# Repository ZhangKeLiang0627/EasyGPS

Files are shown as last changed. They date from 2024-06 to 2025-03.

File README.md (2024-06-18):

# EASY-GPS

### 本项目基于：X-TRACK & CHAPPIE

### Author: kkl

---

视频介绍：[戳这儿:)](https://www.bilibili.com/video/BV1M44219745/)

硬件开源：[戳这里:P](https://oshwhub.com/hugego/easygps-ji-yu-esp32s3-de-gps-zhui-zong-qi)

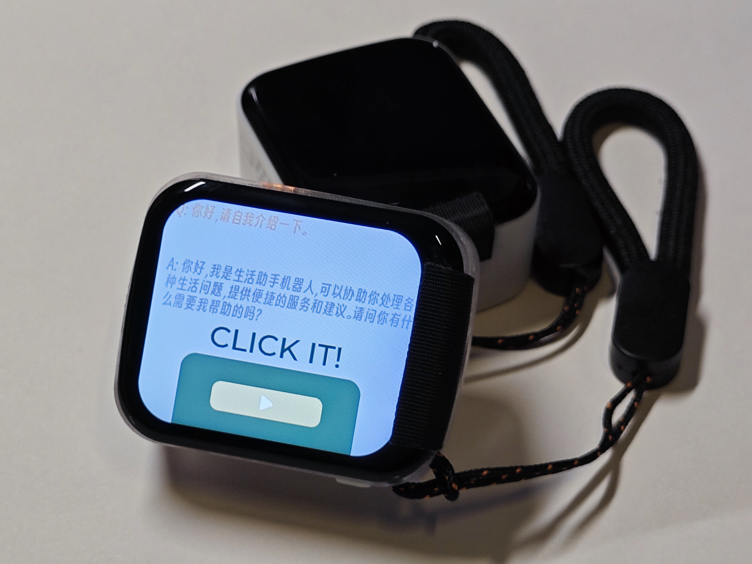
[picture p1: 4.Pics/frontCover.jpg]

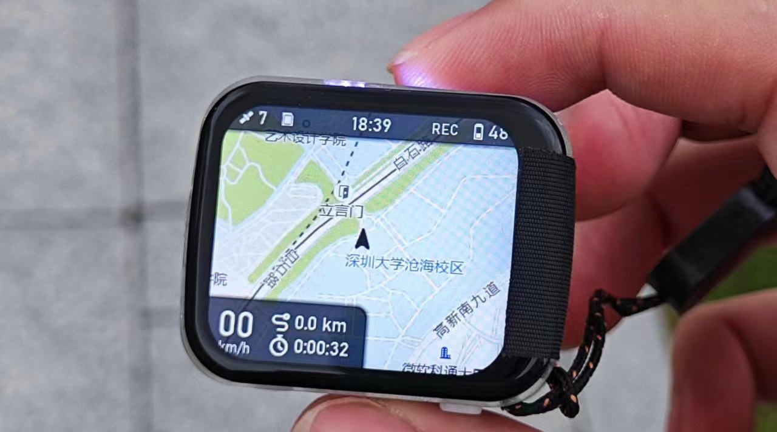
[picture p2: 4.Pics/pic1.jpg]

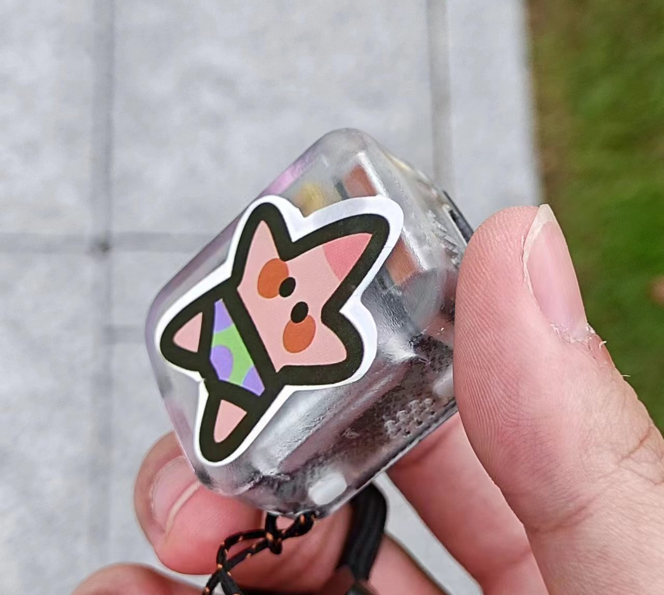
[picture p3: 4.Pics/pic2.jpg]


## 源码文件树
```bash
EasyGPS/
├─lib
│  ├─ESP32-BLE-Combo
│  ├─FastLED
│  ├─NimBLE-Arduino
│  ├─QMC5883LCompass
│  └─TinyGPSPlus
├─src
│  ├─App  
│  └─ChappieCore
├── platformio.ini
```

## TF卡文件树
```bash
MicroSDcard/
├─FONT
│  └─font_smileysd_16.bin
├─MAP
├─SystemSave.json
└─.SystemSaveBackup.json
```

## 思维导图
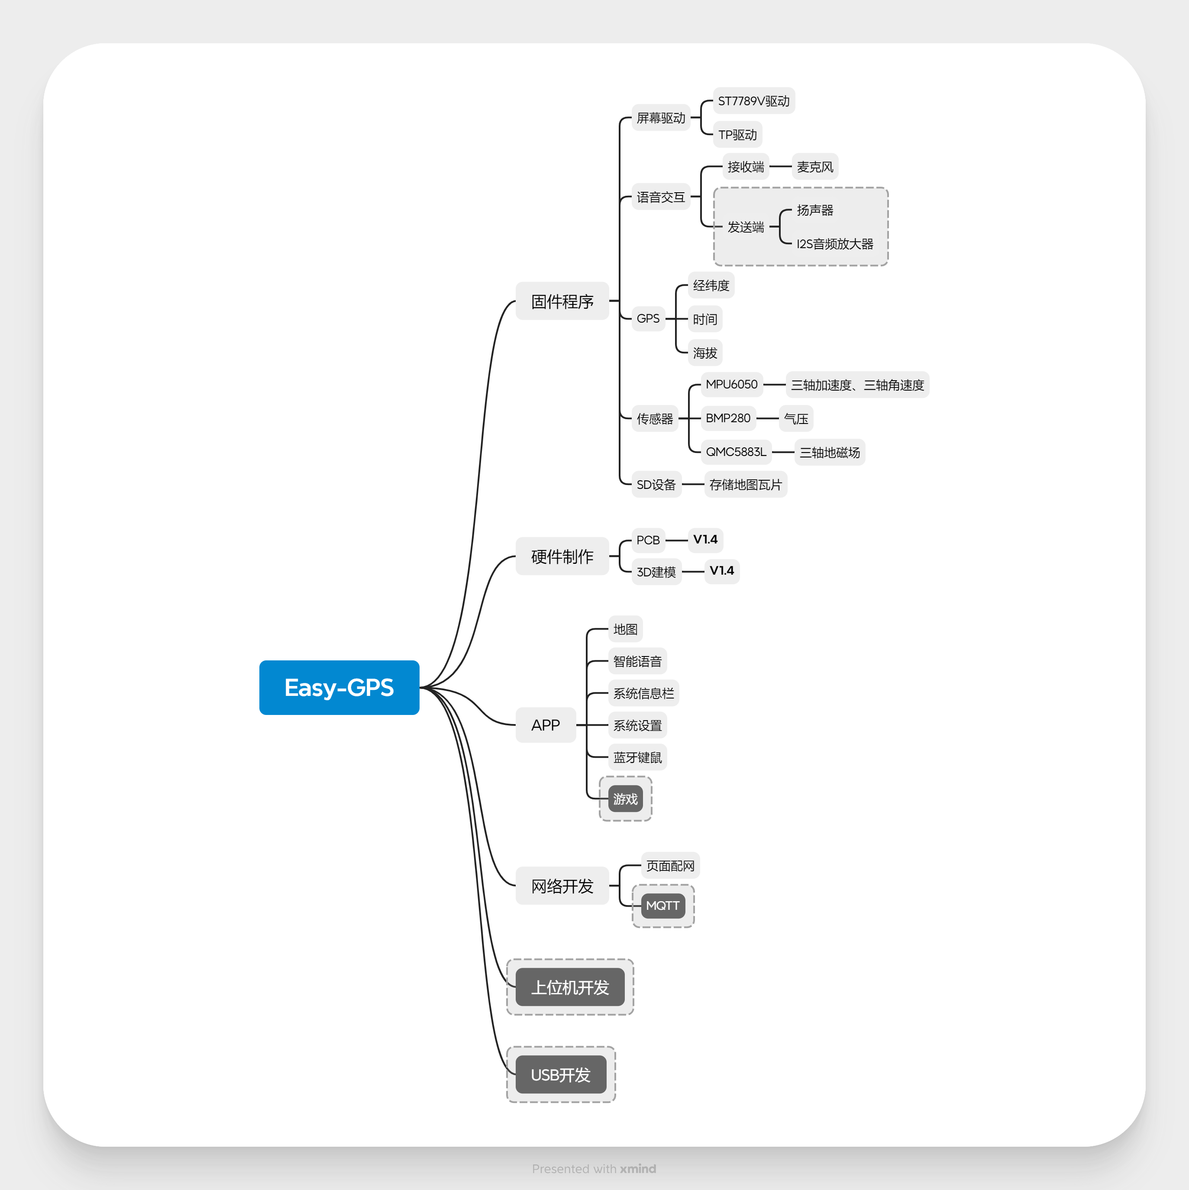
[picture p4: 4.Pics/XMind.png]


## 鸣谢
- 感谢[@FASTSHIFT](https://github.com/FASTSHIFT)的[X-TRACK](https://github.com/FASTSHIFT/X-TRACK)项目：提供了本项目的大致框架。
- 感谢[@Forairaaaaa](https://github.com/Forairaaaaa)的[Chappie-Core](https://github.com/Forairaaaaa/Chappie-Core)项目：提供了ESP32S3在Arduino开发框架的BSP，同时提供硬件的参考设计。
- 感谢[@启凡科创](https://oshwhub.com/dhx233/works)的[QF-HEYE](https://oshwhub.com/dhx233/gai-ban-re-cheng-xiang)项目：提供了部分硬件的参考设计。
- 感谢[@Yeely0162](https://github.com/Yeely0162)开源了ESP32进行WiFi连接时的Web端设计。

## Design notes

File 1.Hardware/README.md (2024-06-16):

# 【EASY-GPS】基于ESP32S3的GPS定位器 

### 本项目基于：X-TRACK & CHAPPIE

### Author: kkl

---

> 压缩包(Version: 1.4)可直接用于立创PCB下单！

视频介绍：[戳这儿:)](https://www.bilibili.com/video/BV1M44219745/)

硬件开源：[戳这里:P](https://oshwhub.com/hugego/easygps-ji-yu-esp32s3-de-gps-zhui-zong-qi)

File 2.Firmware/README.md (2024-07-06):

#### 编译该源码需要注意 lib/lv_conf.h

- 需要将 `lv_conf.h` 放在lvgl库文件夹的同一目录：  .pio/libdeps/esp32-s3-devkitc-1

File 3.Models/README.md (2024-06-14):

#### button.stl 需要修剪
- button.stl 当中有两颗按钮，我们需要将中间的连接件分离。
- 对每颗按钮的外延边进行修剪，剪成呈梯形状即可。

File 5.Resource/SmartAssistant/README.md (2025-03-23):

## 关于智能语音助手SmartAssistant的使用方法

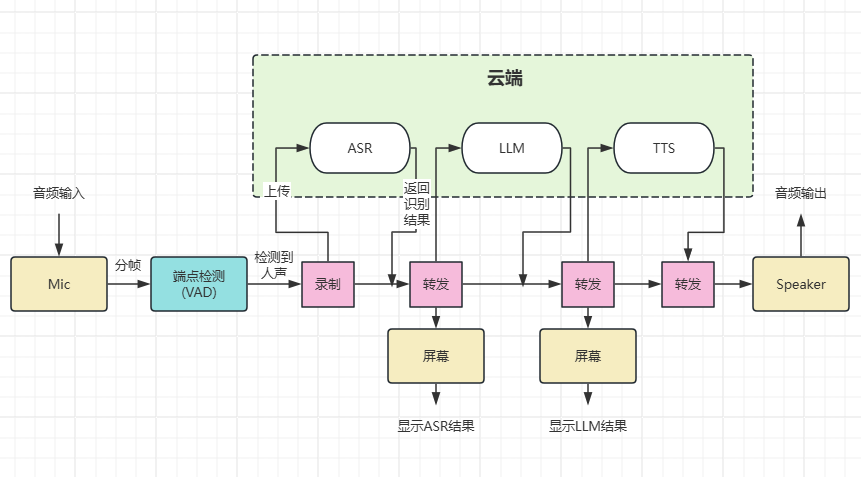
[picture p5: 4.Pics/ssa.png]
ssa流程


### 1. 获得密钥

- 百度在线语音识别 & 百度在线语音合成（共用一套密钥）

> 请您[戳这里:)](https://zhangkeliang0627.github.io/2024/03/24/ESP32S3%E6%8E%A5%E5%85%A5%E7%99%BE%E5%BA%A6%E5%9C%A8%E7%BA%BF%E8%AF%AD%E9%9F%B3%E8%AF%86%E5%88%AB/README/)了解密钥的详细获取方法！

- 文心一言API

> 请您[戳这里:)](https://zhangkeliang0627.github.io/2024/03/25/ESP32S3%E6%8E%A5%E5%85%A5%E6%96%87%E5%BF%83%E4%B8%80%E8%A8%80/README/)了解密钥的详细获取方法！

### 2. 填入密钥

请分别前往源码:
- `src/ChappieCore/SmartAssistantAPI/BaiduASR`
- `src/ChappieCore/SmartAssistantAPI/BaiduTTS`
- `src/ChappieCore/SmartAssistantAPI/BaiduErnieBot`

找到对应的`gainToken`函数，替换您自己的密钥。

### 3. 上机调试
基本上按步骤到这里就可以成功啦，如果没有成功使用智能语音助手，请考虑是否连上WiFi、密钥是否输入正确、账户是否有领取免费次数等原因。祝您复刻成功！

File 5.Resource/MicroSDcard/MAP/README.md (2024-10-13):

### 关于MAP
- 由于体积原因，请自行下载地图瓦片到此处！
- 原生项目`X-TRACK`的地图下载说明：[戳这儿!](https://github.com/FASTSHIFT/X-TRACK/tree/main/Tools)
- `Crimson/地图下载器`的下载地址：[在这儿!](https://gitee.com/CrimsonHu/java_map_download/)

### 注意事项
本项目与原生项目的地图下载大相径庭，跟着说明走就行，只有几点需要注意一下：

- 地图瓦片格式转换时注意选择`Binary RGB565`，否则在EasyGPS上显示是反色的效果。

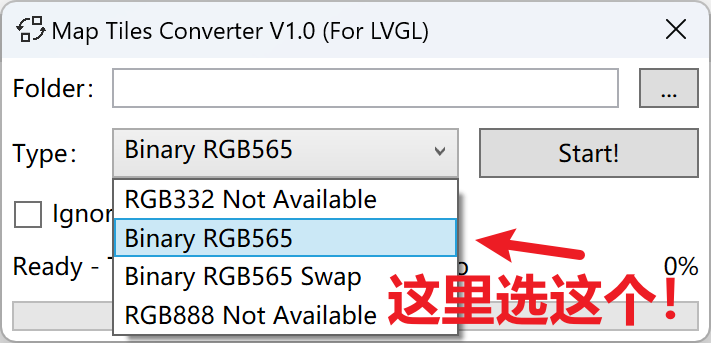
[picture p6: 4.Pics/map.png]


- SD卡的内存应当 ≤ 32GB，SD卡需要格式化为FAT32格式。

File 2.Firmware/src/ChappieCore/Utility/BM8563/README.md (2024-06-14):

Thanks to: https://github.com/tanakamasayuki/I2C_BM8563.git

# I2C BM8563 RTC Library

This is a library of BM8563, the RTC for I2C connectivity.

## Support Devices

- [M5Stack M5Stick](https://docs.m5stack.com/#/en/core/m5stickc)
- [M5Stack M5Stick Plus](https://docs.m5stack.com/#/en/core/m5stickc_plus)
- [M5Stack Core2](https://docs.m5stack.com/#/en/core/core2)
- [M5Stack Timer Camera](https://docs.m5stack.com/#/en/unit/timercam)
- [M5Stack Timer Camera X](https://docs.m5stack.com/#/en/unit/timercam_x)
- [M5Stack CoreInk](https://docs.m5stack.com/#/en/core/coreink)

## Usage
```c
#include "I2C_BM8563.h"
#include <WiFi.h>

// RTC BM8563 I2C port
// I2C pin definition for M5Stick & M5Stick Plus & M5Stack Core2 & M5Stack Core.Ink
#define BM8563_I2C_SDA 21
#define BM8563_I2C_SCL 22

// I2C pin definition for M5Stack TimerCam
// #define BM8563_I2C_SDA 12
// #define BM8563_I2C_SCL 14

I2C_BM8563 rtc(I2C_BM8563_DEFAULT_ADDRESS, Wire1);

const char* ntpServer = "time.cloudflare.com";

void setup() {
  // Init Serial
  Serial.begin(115200);
  delay(50);

  // Connect to an access point
  WiFi.begin();                 // Connect to the access point of the last connection
  //WiFi.begin("SSID", "KEY");  // Or, Connect to the specified access point

  Serial.print("Connecting to Wi-Fi ");
  while (WiFi.status() != WL_CONNECTED) {
    delay(500);
    Serial.print(".");
  }
  Serial.println(" CONNECTED");

  // Set ntp time to local
  configTime(9 * 3600, 0, ntpServer);

  // Init I2C
  Wire1.begin(BM8563_I2C_SDA, BM8563_I2C_SCL);

  // Init RTC
  rtc.begin();

  // Get local time
  struct tm timeInfo;
  if (getLocalTime(&timeInfo)) {
    // Set RTC time
    I2C_BM8563_TimeTypeDef timeStruct;
    timeStruct.hours   = timeInfo.tm_hour;
    timeStruct.minutes = timeInfo.tm_min;
    timeStruct.seconds = timeInfo.tm_sec;
    rtc.setTime(&timeStruct);

    // Set RTC Date
    I2C_BM8563_DateTypeDef dateStruct;
    dateStruct.weekDay = timeInfo.tm_wday;
    dateStruct.month   = timeInfo.tm_mon + 1;
    dateStruct.date    = timeInfo.tm_mday;
    dateStruct.year    = timeInfo.tm_year + 1900;
    rtc.setDate(&dateStruct);
  }
}

void loop() {
  I2C_BM8563_DateTypeDef dateStruct;
  I2C_BM8563_TimeTypeDef timeStruct;

  // Get RTC
  rtc.getDate(&dateStruct);
  rtc.getTime(&timeStruct);

  // Print RTC
  Serial.printf("%04d/%02d/%02d %02d:%02d:%02d\n",
                dateStruct.year,
                dateStruct.month,
                dateStruct.date,
                timeStruct.hours,
                timeStruct.minutes,
                timeStruct.seconds
               );

  // Wait
  delay(1000);
}
```

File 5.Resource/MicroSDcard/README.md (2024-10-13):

## TF卡文件树
```bash
MicroSDcard/
├─FONT
│  └─font_smileysd_16.bin
├─MAP
├─EasyGPS
├─SystemSave.json
└─.SystemSaveBackup.json
```

## 提醒
- 请按照上述文件夹格式制作您的TF卡内容。
- 地图功能和智能语音助手需要使用TF卡资源，请插卡后使用。
- 请在制作TF卡内容时手动创建`EasyGPS`文件夹，创建完成后用于保存路径轨迹`gpx`格式文件，**请手动创建，否则无法正常保存轨迹文件。**

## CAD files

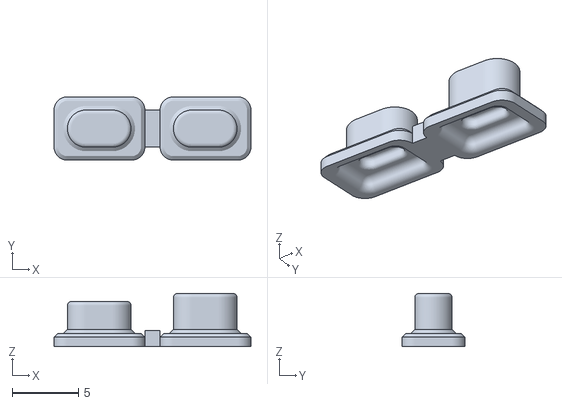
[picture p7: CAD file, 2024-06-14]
3.Models/button.stl
14.9 x 4.77 x 4.00

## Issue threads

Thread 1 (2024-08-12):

question

skipguy, 2024-08-12:
请问我把硬件组装好，然后把TF卡里的文件放好，EasyGPS就可以用了吗，非科班，不太懂代码，但是想尝试复现一下哈
还有一个问题，就是如果没有裝气压和地磁场的模块，那么其他功能还可以正常运行吗，感觉导航这两者用处不大

ZhangKeLiang0627, 2024-08-12:
> 请问我把硬件组装好，然后把TF卡里的文件放好，EasyGPS就可以用了吗，非科班，不太懂代码，但是想尝试复现一下哈 还有一个问题，就是如果没有裝气压和地磁场的模块，那么其他功能还可以正常运行吗，感觉导航这两者用处不大

A：1. 组装好硬件，安装好TF卡后，还需要对芯片进行烧录，您需要将仓库当中的firmware进行编译，编译平台是PlatformIO+Arduino；2. 没有安装上述模块，其他功能也可以正常运行的。

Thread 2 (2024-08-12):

another

skipguy, 2024-08-12:

skipguy, 2024-08-12:
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
大佬，请问BOM里第10个元件《Short_0.6》具体是什么呀，我在淘宝和立创商城是都没有找到，能否指条明路，谢谢！

skipguy, 2024-08-13:
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
佬，q请问这里的tp驱动具体是指什么呀，没能在bom中找到

ZhangKeLiang0627, 2024-08-13:
@skipguy A: 1. Short_0.6是短接焊盘，是当你焊接完成后，上电测试确保VBUS无短路，同时电源管理芯片正常工作时，用焊锡将这个焊盘进行短接即可，作用是防止短路发生时连带烧坏主控等一众芯片；2. TP驱动是指TouchPad，触摸驱动，这个模块已经集成在屏幕当中，不需要理会。

skipguy, 2024-08-18:
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
大佬可以分享下这个文件吗，我元件都买来了，但是不知道哪个焊哪里，请问有没有电子元件对应位置的图？

skipguy, 2024-08-18:
哦，大佬。我已经找到了，谢谢你

ZhangKeLiang0627, 2024-08-19:
> 哦，大佬，我已经找到了，谢谢你的开源！！！给我这个暑假提供了最大的乐趣！

谢谢你的喜欢！

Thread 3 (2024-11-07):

lv_config.h文件夹放置路径导致的编译错误问题

jhnmyr233, 2024-11-07:
当其位于：2.Firmware\lib\lv_conf.h，编译导致出错，如图。
将其位置更改为：2.Firmware\.pio\libdeps\esp32-s3-devkitc-1\lvgl\src\lv_conf.h ，方可成功编译。
我在其他的使用platformio管理的项目中也遇到过类似的问题，比较玄学，希望您可以在您的环境下测试一下，看看是什么结果。
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

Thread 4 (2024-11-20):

LCD与TFcard硬件引脚功能未注明

jhnmyr233, 2024-11-20:
引脚如下:

- LCD_CS
- LCD_BL
- LCD-DC
- LCD-SCL
- LCD-SDA
- LCD-RST
- TP-SCL
- TP-SDA
- TP-RST
- TP-INT
- LCD-EN

部分引脚命名与ST7789V数据手册内的引脚注名不相符，我到现在没理清头绪 :(
出于代码改动的需求，希望作者能够对每个引脚做一下功能标注。
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

ZhangKeLiang0627, 2024-11-21:
朋友你好:)，关于你的提问，我也一时无法详细地参照ST7789V芯片手册给到你回答。但是引脚的命名我是参照屏幕厂家给出的引脚定义的，希望能给到你一些参考，如图：
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

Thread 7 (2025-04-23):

WiFi、AP & BLE 功能打开后导致 ESP32 重启

yuangezhizao, 2025-04-23:
环境：正面元件全部焊接，背面没有焊接，因此源码中注释了`// Gps.init();`和`// Sd.init();`
烧录后发现`WiFi`相关报错，`RT`，于是又注释了`Wf.Init();`，其他源码没有任何修改
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

复现：测试各个传感器发现，在屏幕上进入语音助手会导致重启，报错堆栈如下
``` bash
Guru Meditation Error: Core  1 panic'ed (LoadProhibited). Exception was unhandled.

Core  1 register dump:
PC      : 0x42012bd6  PS      : 0x00060e30  A0      : 0x82032902  A1      : 0x3fcc2780
A2      : 0x00000000  A3      : 0x3fcc27d0  A4      : 0xa4e8aa18  A5      : 0x0000003a
A6      : 0xffff3fff  A7      : 0x00000001  A8      : 0xe27256ac  A9      : 0x0000ffdc
A10     : 0xfffffff0  A11     : 0x3fcc29d4  A12     : 0x00000000  A13     : 0x00080000
A14     : 0x00000018  A15     : 0x3fca6648  SAR     : 0x00000020  EXCCAUSE: 0x0000001c
EXCVADDR: 0xe27256ac  LBEG    : 0x4203466c  LEND    : 0x42034679  LCOUNT  : 0x00000003

Backtrace: 0x42012bd3:0x3fcc2780 0x420328ff:0x3fcc27a0 0x420329be:0x3fcc27d0 0x4203508a:0x3fcc2800 0x42035476:0x3fcc2840 0x42036ea8:0x3fcc2880 0x420377c1:0x3fcc2920 0x4211f43e:0x3fcc2990 0x42025e71:0x3fcc29b0 0x42025fdb:0x3fcc29d0 0x4202d92e:0x3fcc2a10 0x4202dfb7:0x3fcc2a40 0x4202e7ba:0x3fcc2a60 0x42010481:0x3fcc2a80 0x420106f3:0x3fcc2aa0 0x4200ff8e:0x3fcc2f00 0x420156de:0x3fcc2f20 0x420157ee:0x3fcc2f70 0x420152a5:0x3fcc2f90 0x42015639:0x3fcc2fb0 0x4201210b:0x3fcc2fe0 0x42025f45:0x3fcc3000 0x42025fdb:0x3fcc3020 0x420267c3:0x3fcc3060 0x42027110:0x3fcc30a0 0x40377453:0x3fcc30f0 0x4201aaae:0x3fcc3120

ELF file SHA256: 374021e525d0ba0e

Rebooting...
ESP-ROM:esp32s3-20210327
Build:Mar 27 2021
rst:0xc (RTC_SW_CPU_RST),boot:0xb (SPI_FAST_FLASH_BOOT)
Saved PC:0x42123b36
SPIWP:0xee
mode:DIO, clock div:1
load:0x3fce3808,len:0x44c
load:0x403c9700,len:0xbe4
load:0x403cc700,len:0x2a68
entry 0x403c98d4
[Power] Voltage:4.30 V
```

排查：翻立创帖子以为是需要先配网才能用语音助手，于是尝试在屏幕上开启`AP`发现又重启了，后发现开启 WiFi、AP 和 BLE 的开关后都会导致重启（代码中调用`Wf.Init();`,`Wf.APMode();`之类的就会），但是看不到具体报错堆栈……

不太会用`ESP32`的`debug`，打了断点却停在了奇怪的位置，`USB`串口还无了，重新使用`TTL`烧录固件后才能用`USB`串口，请问应该如何排查？

yuangezhizao, 2025-04-23:
再确认下`π`网络的取值，最开始我给`R25`和`R26`焊接了`0Ω`电阻，后来发现应该是空着不焊接吧
立创的帖子`0Ω`电阻指的是`R23`吧，最开始是理解错了

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

ZhangKeLiang0627, 2025-04-23:
您好，感谢提出问题。

设备倘若要使用WiFi、GPS、BLE是需要接入电池（默认3.7V的锂电池600mAh，刚好塞满外壳内部空间）的，否则会因为供电不足而导致ESP32重启。

仓库当中有提到，如果您要使用地图和智能语音对话助手功能，是需要使用到SD卡内的资源的，这要求您将仓库内与SD卡相关的内容拷贝到您的SD卡当中并插入设备后再启动，使之能够读取加载SD卡中的资源（主要是中文字库）。没有加载字库无法打开语音对话助手应用，会报错而重启。

智能语音助手功能需要您去配置对应百度智能云的ASR+TTS、LLM的Key，并按照仓库当中的说明指引填到源代码的对应位置去才可启用智能语音助手。

ZhangKeLiang0627, 2025-04-23:
> 再确认下`π`网络的取值，最开始我给`R25`和`R26`焊接了`0Ω`电阻，后来发现应该是空着不焊接吧 立创的帖子`0Ω`电阻指的是`R23`吧，最开始是理解错了
>
> 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

对的，0Ω电阻指的是R23

yuangezhizao, 2025-04-26:
前几天把背面元件全部焊接完成并插入电池后，`WiFi`、`AP`&`BLE`功能就可以正常使用了，看来确实是供电不足 :(
P.S. 这个`CA-C03`贴片天线信号看起来应该是正常的吧，和`AP`是在同一间屋子里，信号强度`-33dbm`

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

<hr>

最后，想再问下是一定需要接入电池还是如果`USB`供电足够就可以支撑？
看原理图上`USB`的`VBUS`输入经过`SGM4056`给到`BAT`，然后给`ESP32`供电的`VDD3V3`是电池输入经过`SGM6036`后得到的吧
所以，是没接入电池时`SGM4056`的输出不够？不知道我理解的对不对

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

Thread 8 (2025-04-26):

使用 SmartAssistant 中 ASR 报错后，疑似内存不足导致 ESP32 重启

yuangezhizao, 2025-04-26:
环境：`BaiduASR.cpp`中配置好了`client_id`和`client_secret`后烧录程序，账户中有「短语音识别极速版」的免费额度，但是目前只配置了`ASR`

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

<hr>

复现：开机后首先连接`WiFi`，然后进入`SmartAssistant`功能

- 第一次，报错`token`失效，奇怪`token`应该是存在`Preferences`中的，而不用每次重启时都要重新获取吧

<details>

``` bash
LocalIP:192.168.2.242
[DP] WiFiPULL
[Model] GetWiFiInfo
[DP] BLE PULL
[Model] GetBLEInfo
[DP] BacklightPULL
[Model] GetDisplayBrightness
[Power] Voltage: 3.64 V
[Power] Voltage: 3.63 V
[DP] SmartAssistantPULL
[Model] GetSmartAssistantInfo
[DP] SmartAssistantPULL
[Model] GetSmartAssistantInfo
[DP] SmartAssistantNOTOFIY
Helloworld and none!
[Talk] Talk Start!
[Mic] Record begin!
[Model] SetSmartAssistantBegin
[Mic] record: true count: 0
[Mic] rms:16704.99
[Mic] record: true count: 1
[Mic] rms:1196.53
[Mic] record: true count: 2
[Mic] rms:1206.58
[Mic] record: true count: 3
[Mic] rms:1208.49
[Mic] record: true count: 4
[Mic] rms:1205.96
[Mic] record: true count: 5
[Power] Voltage: 3.63 V
[Mic] rms:1205.36
[Mic] record: true count: 6
[Mic] rms:1207.05
[Mic] record: true count: 7
[DP] SmartAssistantPULL
[Model] GetSmartAssistantInfo
[Mic] rms:1205.74
[Mic] record: true count: 8
[Mic] rms:1208.12
[Mic] record: true count: 9
[Mic] rms:1205.86
[Mic] record: true count: 10
[Mic] rms:1206.78
[Mic] record: true count: 11
[Mic] rms:1204.41
[Mic] record: true count: 12
[Mic] rms:1205.42
[Mic] record: true count: 13
[Mic] rms:1206.40
[Mic] record: true count: 14
[Mic] rms:1207.74
[Mic] record: true count: 15
[Mic] rms:1206.70
[Mic] record: true count: 16
[Mic] rms:1205.19
[Mic] record: true count: 17
[Mic] rms:1204.32
[Mic] record: true count: 18
[Mic] rms:1204.38
[Mic] record: true count: 19
[Mic] rms:1204.86
[Mic] record: true count: 20
[Mic] rms:1203.60
[Mic] record: true count: 21
[Mic] rms:1204.81
[Mic] record: true count: 22
[DP] SmartAssistantPULL
[Model] GetSmartAssistantInfo
[Mic] rms:1206.05
[Mic] record: true count: 23
[Mic] rms:1206.40
[Mic] record: true count: 24
[Mic] rms:1206.58
[Mic] record: true count: 25
[Mic] rms:1205.45
[Mic] record: true count: 26
[Mic] rms:1203.86
[Mic] record: true count: 27
[Mic] rms:1205.02
[Mic] record: true count: 28
[Mic] rms:1205.83
[Mic] record: true count: 29
[Mic] rms:1205.05
[Mic] record: true count: 30
[Mic] rms:1204.22
[Mic] record: true count: 31
[Mic] rms:1205.85
[Mic] record: true count: 32
[Mic] rms:1203.97
[Mic] record: true count: 33
[Mic] rms:1207.03
[Mic] record: true count: 34
[Mic] rms:1207.41
[Mic] record: true count: 35
[Mic] rms:1205.19
[Mic] record: true count: 36
[Mic] rms:1204.88
[Mic] record: true count: 37
[Power] Voltage: 3.63 V
[Mic] rms:1204.25
[Mic] record: true count: 38
[DP] SmartAssistantPULL
[Model] GetSmartAssistantInfo
[Mic] rms:1206.36
[Mic] record: true count: 39
[Mic] rms:1205.87
[Mic] record: true count: 40
[Mic] rms:1203.81
[Mic] record: true count: 41
[Mic] rms:1205.49
[Mic] record: true count: 42
[Mic] rms:1203.24
[Mic] record: true count: 43
[Mic] rms:1206.33
[Mic] record: true count: 44
[Mic] rms:1205.16
[Mic] record: true count: 45
[Mic] rms:1203.91
[Mic] record: true count: 46
[Mic] rms:1201.70
[Mic] record: true count: 47
[Mic] rms:1207.98
[Mic] record: true count: 48
[Mic] rms:1204.68
[Mic] record: true count: 49
[Mic] rms:1204.61
[Mic] record: true count: 50
[Mic] rms:1206.35
[Mic] record: true count: 51
[Mic] rms:1207.26
[Mic] record: true count: 52
[Mic] rms:1205.44
[Mic] record: true count: 53
[Mic] rms:1205.68
[Mic] record: true count: 54
[DP] SmartAssistantPULL
[Model] GetSmartAssistantInfo
[Mic] rms:1205.31
[Mic] record: true count: 55
[Mic] rms:1205.20
[Mic] record: true count: 56
[Mic] rms:1203.95
[Mic] record: true count: 57
[Mic] rms:1205.91
[Mic] record: true count: 58
[Mic] rms:1205.05
[Mic] record: true count: 59
[Mic] rms:1206.48
[Mic] record: true count: 60
[Mic] rms:1204.74
[Mic] record: true count: 61
[Mic] rms:1205.49
[Mic] record: true count: 62
[Mic] rms:1205.11
[Mic] record: true count: 63
[Mic] rms:1207.64
[Mic] record: true count: 64
[Mic] rms:1204.83
[Mic] record: true count: 65
[Mic] rms:1204.68
[Mic] record: true count: 66
[Mic] rms:1206.24
[Mic] record: true count: 67
[Mic] rms:1205.31
[Mic] record: true count: 68
[Power] Voltage: 3.65 V
[Mic] rms:1205.31
[Mic] record: true count: 69
[DP] SmartAssistantPULL
[Model] GetSmartAssistantInfo
[Mic] rms:1204.30
[Mic] record: true count: 70
[Mic] rms:1205.34
[Mic] record: true count: 71
[Mic] rms:1202.89
[Mic] record: true count: 72
[Mic] rms:1202.31
[Mic] record: true count: 73
[Mic] rms:1206.99
[Mic] record: true count: 74
[Mic] rms:1205.25
[Mic] record: true count: 75
[Mic] rms:1204.32
[Mic] record: true count: 76
[Mic] rms:1205.30
[Mic] record: true count: 77
[Mic] rms:1206.55
[Mic] record: true count: 78
[Mic] rms:1203.85
[Mic] record: true count: 79
[Mic] rms:1202.96
[Mic] record: true count: 80
[Mic] rms:1205.43
[Mic] record: true count: 81
[Mic] rms:1205.37
[Mic] record: true count: 82
[Mic] rms:1203.25
[Mic] record: true count: 83
[Mic] rms:1205.04
[Mic] record: true count: 84
[Mic] rms:1204.04
[Mic] record: true count: 85
[DP] SmartAssistantPULL
[Model] GetSmartAssistantInfo
[Mic] rms:1205.22
[Mic] record: true count: 86
[Mic] rms:1205.75
[Mic] record: true count: 87
[Mic] rms:1204.86
[Mic] record: true count: 88
[Mic] rms:1203.87
[Mic] record: true count: 89
[Mic] rms:1203.06
[Mic] record: true count: 90
[Mic] rms:1206.96
[Mic] record: true count: 91
[Mic] rms:1205.90
[Mic] record: true count: 92
[Mic] rms:1205.69
[Mic] record: true count: 93
[Mic] rms:1202.16
[Mic] record: true count: 94
[Mic] rms:1204.39
[Mic] record: true count: 95
[Mic] rms:1203.93
[Mic] record: true count: 96
[Mic] rms:1206.57
[Mic] record: true count: 97
[Mic] rms:1206.19
[Mic] record: true count: 98
[Mic] rms:1206.50
[Mic] record: true count: 99
[Mic] rms:1205.87
[Mic] record: true count: 100
[Power] Voltage: 3.63 V
[Mic] rms:1205.69
[Mic] record: true count: 101
[DP] SmartAssistantPULL
[Model] GetSmartAssistantInfo
[Mic] rms:1205.98
[Mic] record: true count: 102
[Mic] rms:1203.46
[Mic] record: true count: 103
[Mic] rms:1204.44
[Mic] record: true count: 104
[Mic] rms:1205.41
[Mic] record: true count: 105
[Mic] rms:1205.57
[Mic] record: true count: 106
[Mic] rms:1205.46
[Mic] record: true count: 107
[Mic] rms:1206.29
[Mic] record: true count: 108
[Mic] rms:1206.34
[Mic] record: true count: 109
[Mic] rms:1205.13
[Mic] record: true count: 110
[Mic] rms:1205.78
[Mic] record: true count: 111
[Mic] rms:1203.58
[Mic] record: true count: 112
[Mic] rms:1205.79
[Mic] record: true count: 113
[Mic] rms:1205.48
[Mic] record: true count: 114
[Mic] rms:1206.71
[Mic] record: true count: 115
[Mic] rms:1204.60
[Mic] record: true count: 116
[DP] SmartAssistantPULL
[Model] GetSmartAssistantInfo
[Mic] rms:1204.43
[Mic] record: true count: 117
[Mic] rms:1206.43
[Mic] record: true count: 118
[Mic] rms:1205.12
[Mic] record: true count: 119
[Mic] rms:1207.12
[Mic] record: true count: 120
[Mic] rms:1203.98
[Mic] record: true count: 121
[Mic] rms:1207.49
[Mic] record: true count: 122
[Mic] rms:1204.89
[Mic] record: true count: 123
[Mic] rms:1205.27
[Mic] record: true count: 124
[Mic] rms:1204.08
[Mic] record: true count: 125
[Mic] rms:1204.83
[Mic] record: true count: 126
[Mic] rms:1209.47
[Mic] record: true count: 127
[Mic] rms:1205.69
[Mic] Finish! recordCountx1024x2:260096
[ASR] Begin!
[ASR] Start recognition!
[Power] Voltage: 3.63 V
[DP] SmartAssistantPULL
[Model] GetSmartAssistantInfo
[DP] SmartAssistantPULL
[Model] GetSmartAssistantInfo
[Power] Voltage: 3.62 V
[DP] SmartAssistantPULL
[Model] GetSmartAssistantInfo
[DP] SmartAssistantPULL
[Model] GetSmartAssistantInfo
[DP] SmartAssistantPULL
[Model] GetSmartAssistantInfo
[Power] Voltage: 3.60 V
[DP] SmartAssistantPULL
[Model] GetSmartAssistantInfo
[DP] SmartAssistantPULL
[Model] GetSmartAssistantInfo
[Power] Voltage: 3.63 V
[DP] SmartAssistantPULL
[Model] GetSmartAssistantInfo
[ASR] Err: 3307

[ASR] Record: , timeSpend: 7621 ms
[GPT] Begin!
[ASR] Err: 110
[DP] SmartAssistantPULL
[Model] GetSmartAssistantInfo
[Power] Voltage: 3.62 V
[DP] SmartAssistantPULL
[Model] GetSmartAssistantInfo
[HTTP] GET... failed, error:
[GPT] Response: token失效了，已尝试重新获取，请试试看吧！, timeSpend: 2018 ms
[DP] SmartAssistantPULL
[Model] GetSmartAssistantInfo
[Power] Voltage: 3.63 V
[DP] SmartAssistantPULL
[Model] GetSmartAssistantInfo
[DP] SmartAssistantPULL
[Model] GetSmartAssistantInfo
[Power] Voltage: 3.63 V
[Talk] Talk complete!
[DP] SmartAssistantPULL
```

</details>

- 第二次，报错`E (102267) esp-sha: Failed to allocate buf memory`应该是内存不足吧，然后就直接重启了

<details>
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
yuangezhizao, 2025-04-26:
查了下文档`[ASR] Err: 3307`可能是`原始音频质量过差`，看来还真有可能是麦克风坏了 :(

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

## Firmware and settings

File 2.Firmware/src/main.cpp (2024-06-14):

#include <Arduino.h>
#include "lvgl.h"
#include "ChappieCore/ChappieCore.h"
#include "App/App.h"
#include "App/Common/HAL/HAL.h"

ChappieCore Chappie;

void setup()
{
  /* Init Chappie Core */
  Chappie.begin();

  /* Connect HAL */
  HAL::HAL_Init();

  /* UI Create */
  App_Init();

  /* Memory Check */
  _LOG("[PSRAM] free PSRAM: %d\r\n", ESP.getFreePsram());
  // Serial.printf("Deafult free size: %d\n", heap_caps_get_free_size(MALLOC_CAP_DEFAULT));
  // Serial.printf("PSRAM free size: %d\n", heap_caps_get_free_size(MALLOC_CAP_SPIRAM));

#if !CHAPPIE_CORE_USE_LVGL_WITHOUT_RTOS
  Chappie.lvgl.enable();
#endif
}

void loop()
{
#if CHAPPIE_CORE_USE_LVGL_WITHOUT_RTOS
  lv_timer_handler();
  delay(1);
#endif
  // HAL::HAL_Update();
  delay(10);
}

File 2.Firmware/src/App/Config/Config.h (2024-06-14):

/*
 * MIT License
 * Copyright (c) 2021 _VIFEXTech
 *
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
 * THE SOFTWARE IS PROVIDED "AS IS", WITHOUT WARRANTY OF ANY KIND, EXPRESS OR
 * IMPLIED, INCLUDING BUT NOT LIMITED TO THE WARRANTIES OF MERCHANTABILITY,
 * FITNESS FOR A PARTICULAR PURPOSE AND NONINFRINGEMENT. IN NO EVENT SHALL THE
 * AUTHORS OR COPYRIGHT HOLDERS BE LIABLE FOR ANY CLAIM, DAMAGES OR OTHER
 * LIABILITY, WHETHER IN AN ACTION OF CONTRACT, TORT OR OTHERWISE, ARISING FROM,
 * OUT OF OR IN CONNECTION WITH THE SOFTWARE OR THE USE OR OTHER DEALINGS IN THE
 * SOFTWARE.
 */
#ifndef __CONFIG_H
#define __CONFIG_H

/*=========================
   Application configuration
 *=========================*/

#define CONFIG_SYSTEM_SAVE_FILE_PATH          "/SystemSave.json"
#define CONFIG_SYSTEM_SAVE_FILE_BACKUP_PATH   "/.SystemSaveBackup.json"
#define CONFIG_SYSTEM_LANGUAGE_DEFAULT        "en-GB"
#define CONFIG_SYSTEM_TIME_ZONE_DEFAULT       8    // GMT+ 8
#define CONFIG_SYSTEM_SOUND_ENABLE_DEFAULT    true

#define CONFIG_WEIGHT_DEFAULT                 65   // kg

#ifdef ARDUINO
#  define CONFIG_GPS_REFR_PERIOD              2000 // ms
#else
#  define CONFIG_GPS_REFR_PERIOD              10 // ms
#endif

#define CONFIG_GPS_LONGITUDE_DEFAULT          113.945355f
#define CONFIG_GPS_LATITUDE_DEFAULT           22.538667f

#define CONFIG_TRACK_FILTER_OFFSET_THRESHOLD  2 // pixel
#define CONFIG_TRACK_RECORD_FILE_DIR_NAME     "EasyGPS"

#define CONFIG_MAP_USE_WGS84_DEFAULT          false
#define CONFIG_MAP_DIR_PATH_DEFAULT           "/MAP"

#ifndef CONFIG_MAP_EXT_NAME_DEFAULT
#define CONFIG_MAP_EXT_NAME_DEFAULT           "bin"
#endif

#ifndef CONFIG_MAP_IMG_PNG_ENABLE
#  define CONFIG_MAP_IMG_PNG_ENABLE           0
#endif

#define CONFIG_ARROW_THEME_DEFAULT            "default"

#define CONFIG_LIVE_MAP_LEVEL_DEFAULT         16

#define CONFIG_LIVE_MAP_DEBUG_ENABLE          0
#if CONFIG_LIVE_MAP_DEBUG_ENABLE
#  define CONFIG_LIVE_MAP_VIEW_WIDTH          280
#  define CONFIG_LIVE_MAP_VIEW_HEIGHT         240
#else
#  define CONFIG_LIVE_MAP_VIEW_WIDTH          LV_HOR_RES
#  define CONFIG_LIVE_MAP_VIEW_HEIGHT         LV_VER_RES
#endif

#define CONFIG_MONKEY_TEST_ENABLE             0
#if CONFIG_MONKEY_TEST_ENABLE
#  define CONFIG_MONKEY_INDEV_TYPE            LV_INDEV_TYPE_ENCODER
#  define CONFIG_MONKEY_PERIOD_MIN            10
#  define CONFIG_MONKEY_PERIOD_MAX            100
#  define CONFIG_MONKEY_INPUT_RANGE_MIN       -5
#  define CONFIG_MONKEY_INPUT_RANGE_MAX       5
#endif

/* Buzzer */
#define CONFIG_BUZZ_PIN 46
#define CONFIG_BUZZ_CHANNEL 0
#define CONFIG_SOUND_ENABLE_DEFAULT true

#endif

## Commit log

2024-06-14 更新视频链接！
2024-06-16 上传PCB_Gerber文件
2024-06-18 更新README.md（加入思维导图）
2024-07-06 fix(修正相关库丢失的问题)
2024-07-06 fix(修复丢失库的问题)
2024-10-13 ✏️：更新README
2024-10-13 ✏️：更新README，解决无法正常保存轨迹文件的问题。
2024-11-03 ✏️：修复一些细节问题。
2025-03-23 📖：增添图片
